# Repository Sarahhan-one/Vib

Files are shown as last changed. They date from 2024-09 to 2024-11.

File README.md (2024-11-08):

# Vib : Wearable Directional Assistant

Vib_rev2_animation
378704736-dd931122-ff3b-4bf1-a659-7b5e057d0389

## What is Vib? 
Vib is a ```wearable smart anklet``` that navigates the wearer using vibration. 
It houses ```three haptic motors``` facing three different directions – ```left```, ```forward```, and ```right``` – to convey an intuitive sense of direction. 
A smartphone connects to it and enables the navigator mode, as well as the customization of features.

## How it works? 
Vib is powered by a rechargeable battery that uses a type-C charger. The battery powers the microcontroller, the ATmega328P-AU, which controls all inputs and outputs used by Vib as well as the GPS and the bluetooth connection. 

The inputs to the devices are the GPS and the bluetooth signals. 
The bluetooth module allows the user to use the Vib app to cater the device to their needs, including setting the destination and the vibration intensity. 

As the device receives locational and direction information from the phone, it will send corresponding vibrational signals to vibrational motors installed at different sides of the device. 
As well, two LED lights are also used as the outputs of the microcontroller to indicate, for example, the bluetooth or battery status. 



## Future enhancements
* _Real-Time Location_ : Vib will have an embedded GPS module that allows user to track the location of the device real-time.
  This means one can easily find Vib device when lost, as well as the location of the other Vib it is connected to.
* _Connect to Another Vib via Bluetooth_ : Vib will provide an option to connect to another Vib, which allows one to find the location of the other Vib wearer through vibration.
* _Change Vibration Intensity_ : Through the Vib app, one will be able to easily change the vibration intensity. From workouts to daily walks, Vib can be felt in any environment.
* _Change Light Style_ : As well, Vib also offers diverse light modes. One will be able to choose to turn off the LEDs during the day and bright and festive at night.

## Flowchart 


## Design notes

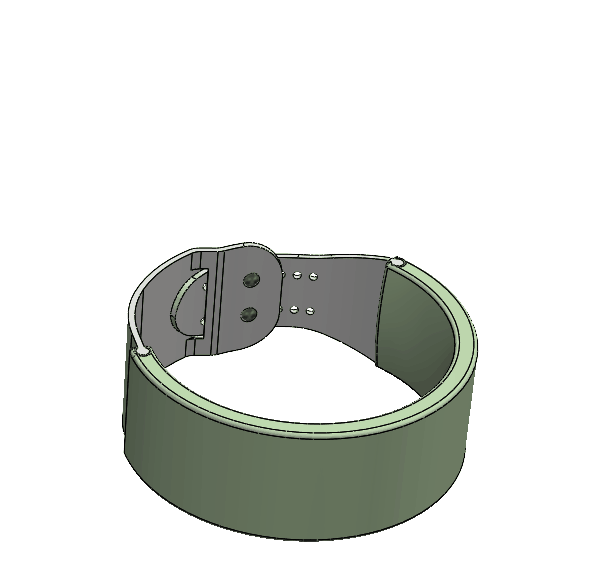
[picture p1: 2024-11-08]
Vib_rev2_explosion.gif

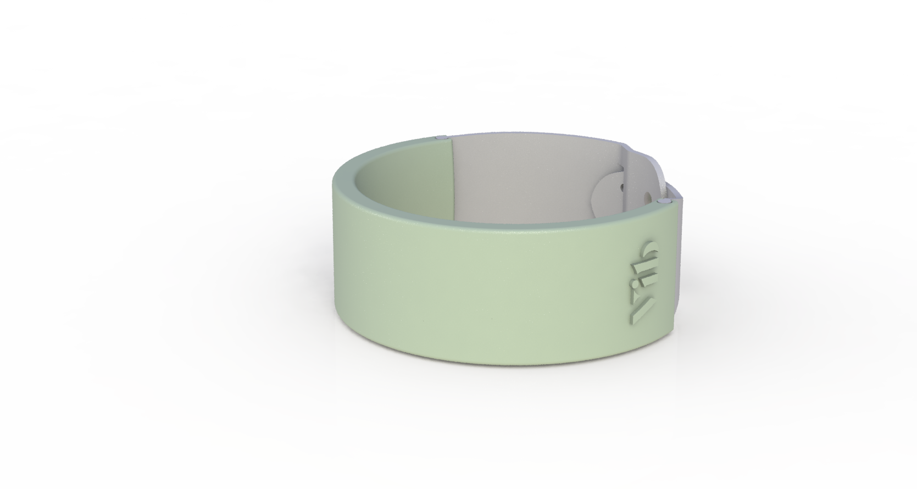
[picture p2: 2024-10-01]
SW_Vib/Vib_rev2/Vib_rev2_green_Studio.png

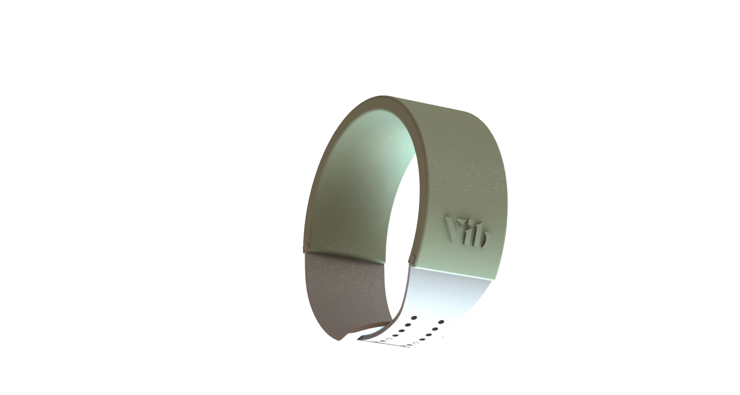
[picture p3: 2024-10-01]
SW_Vib/Vib_rev2/Vib_rev2_green.png

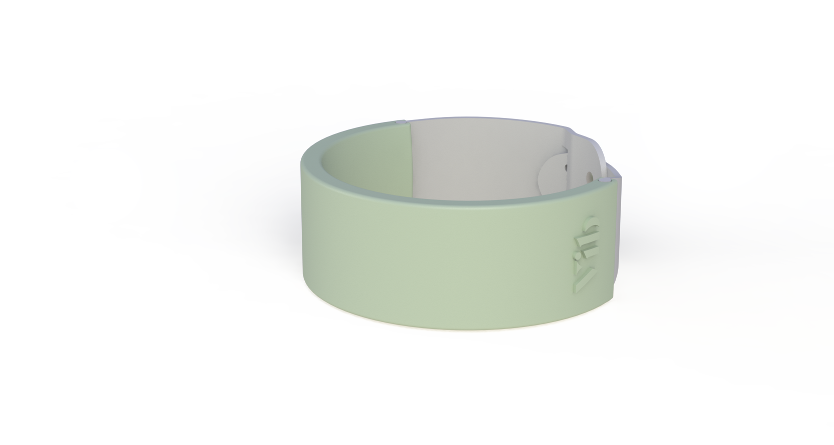
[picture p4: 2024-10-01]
SW_Vib/Vib_rev2/Vib_rev2_green_twolights.png

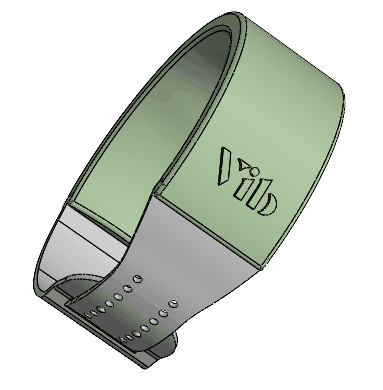
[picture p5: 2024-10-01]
SW_Vib/Vib_rev2/Vib_rev2_animation.gif

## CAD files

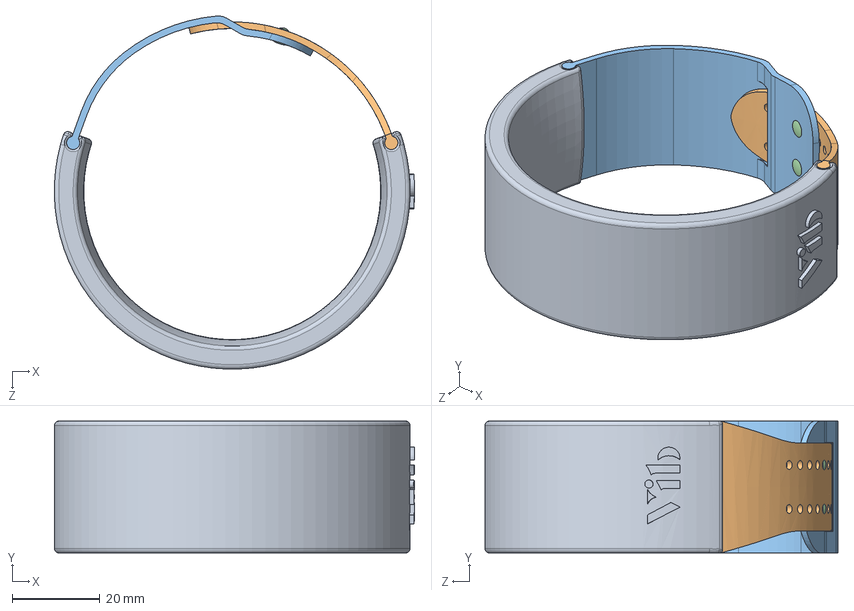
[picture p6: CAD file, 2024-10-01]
SW_Vib/Vib_rev2/SW_files/Vib_rev2.SLDASM
81.9 x 30.0 x 80.3 mm
Vib_Case_Silicon_rev2
NoBuckleStrap_Silicon
BuckleStrap_Silicon
Buckle_StainlessSteel x 2
2mm_Mini_Vibrating_Disk_Motor x 3
A1848_Battery x 2

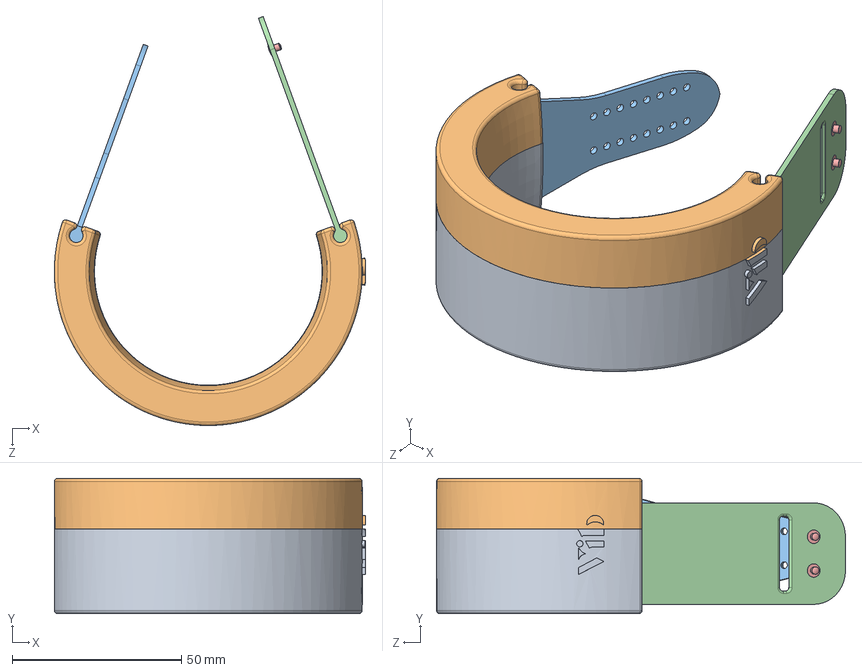
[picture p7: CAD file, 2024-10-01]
SW_Vib/Vib_printing/Vib_printing_SW/Vib_printing.SLDASM
92.0 x 40.0 x 120.8 mm
Vib_Case_printing_lower
Vib_Case_printing_upper
NoBuckleStrap_Silicon_flatten
BuckleStrap_flatten
Buckle_StainlessSteel x 2

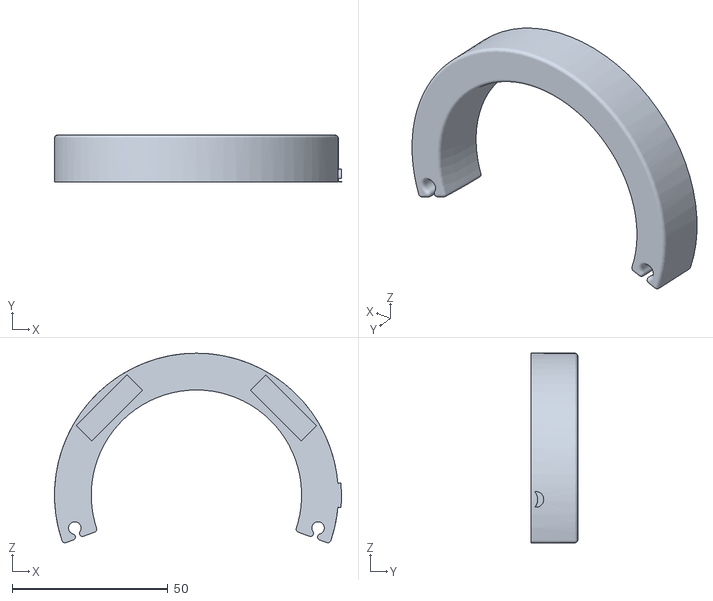
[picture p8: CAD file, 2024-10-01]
SW_Vib/Vib_printing/Vib_Case_printing_upper.STL
92.0 x 15.0 x 60.8

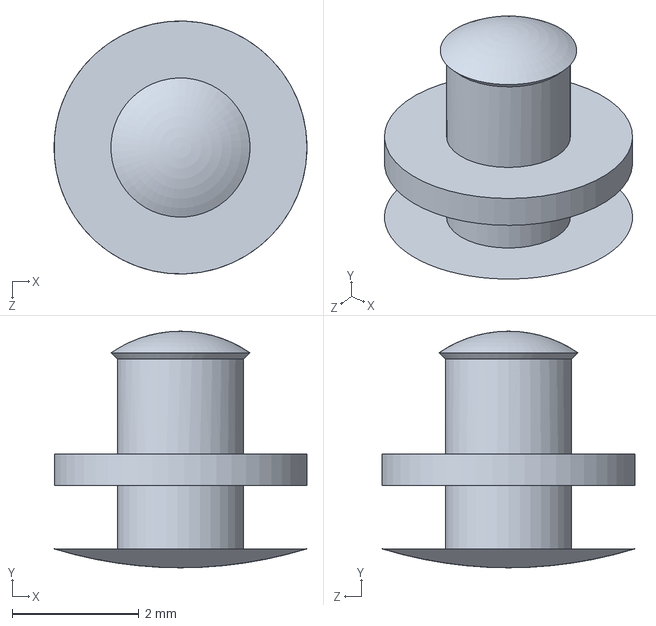
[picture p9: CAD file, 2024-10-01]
SW_Vib/Vib_printing/Vib_printing_SW/Buckle_StainlessSteel.SLDPRT
4.00 x 3.74 x 4.00 mm

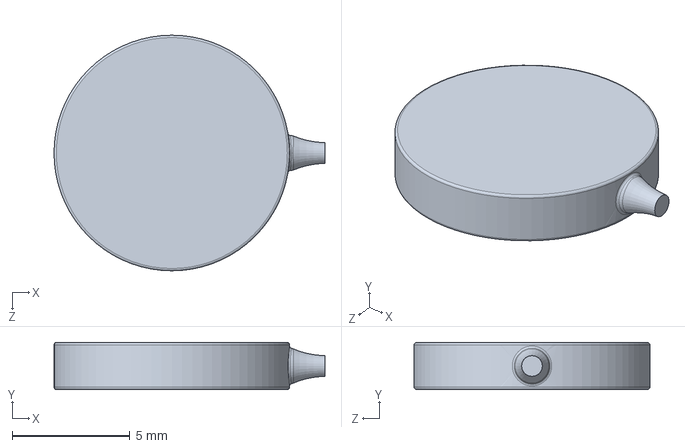
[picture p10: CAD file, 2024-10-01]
SW_Vib/Vib_rev2/SW_files/2mm_Mini_Vibrating_Disk_Motor.SLDPRT
11.5 x 2.00 x 10.0 mm

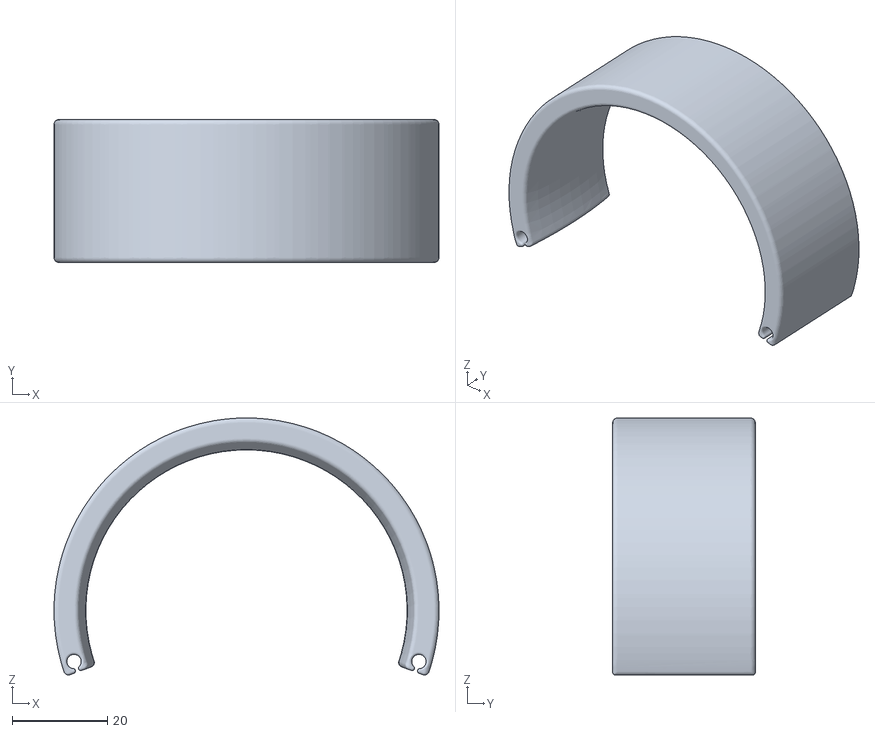
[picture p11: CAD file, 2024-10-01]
SW_Vib/Vib_rev2/Vib_Case_Silicon_rev2.STL
80.9 x 30.0 x 54.0

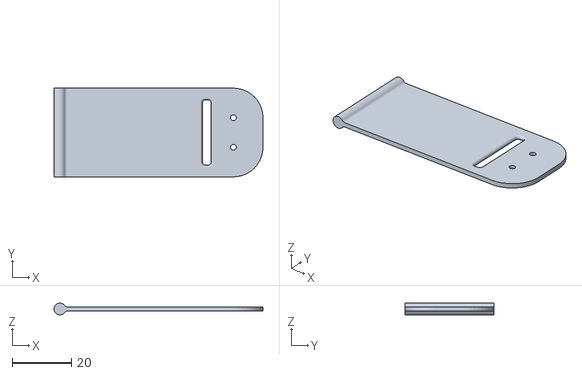
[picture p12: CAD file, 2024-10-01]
SW_Vib/Vib_printing/BuckleStrap_flatten.STL
70.7 x 30.0 x 3.99

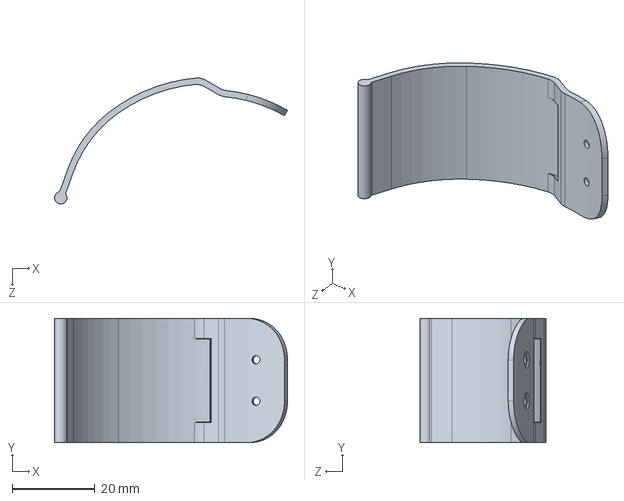
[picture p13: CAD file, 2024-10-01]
SW_Vib/Vib_rev2/SW_files/BuckleStrap_Silicon.SLDPRT
56.1 x 30.0 x 30.4 mm

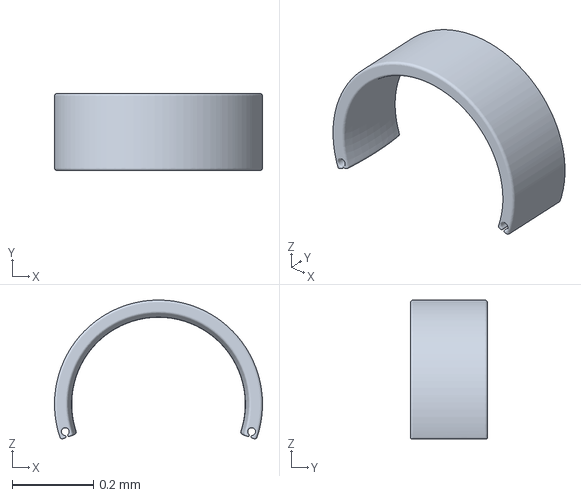
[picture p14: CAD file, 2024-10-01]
SW_Vib/Vib_rev2/Vib_Case_Silicon_rev2_green.3mf
0.512 x 0.19 x 0.342 mm

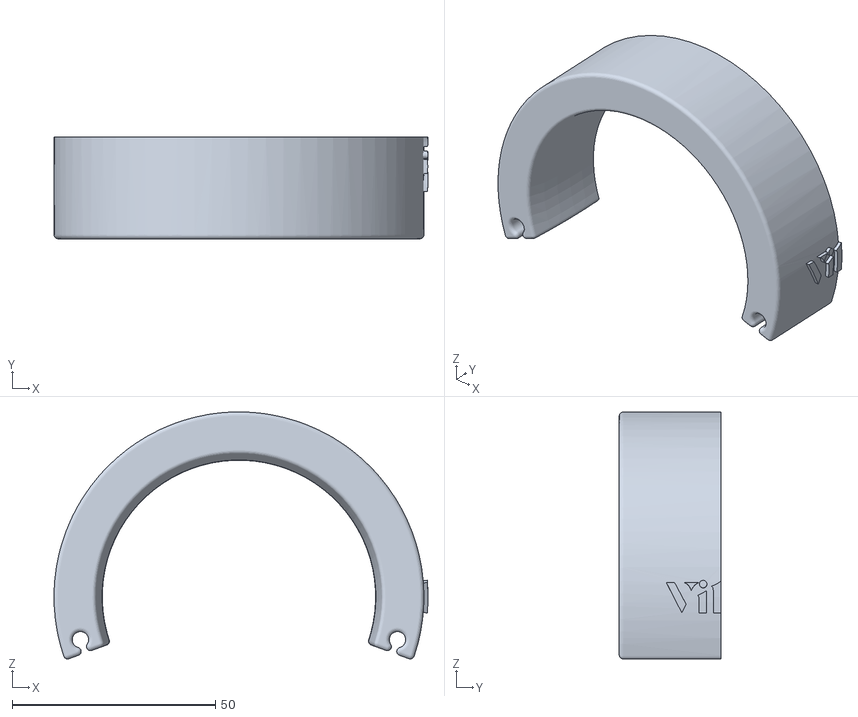
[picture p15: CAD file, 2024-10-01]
SW_Vib/Vib_printing/Vib_Case_printing_lower.STL
92.0 x 25.0 x 60.8

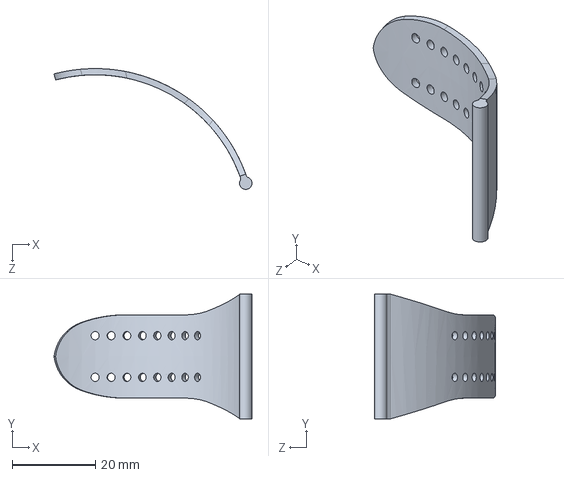
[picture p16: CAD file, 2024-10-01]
SW_Vib/Vib_printing/Vib_printing_SW/NoBuckleStrap_Silicon.SLDPRT
47.5 x 30.0 x 29.0 mm

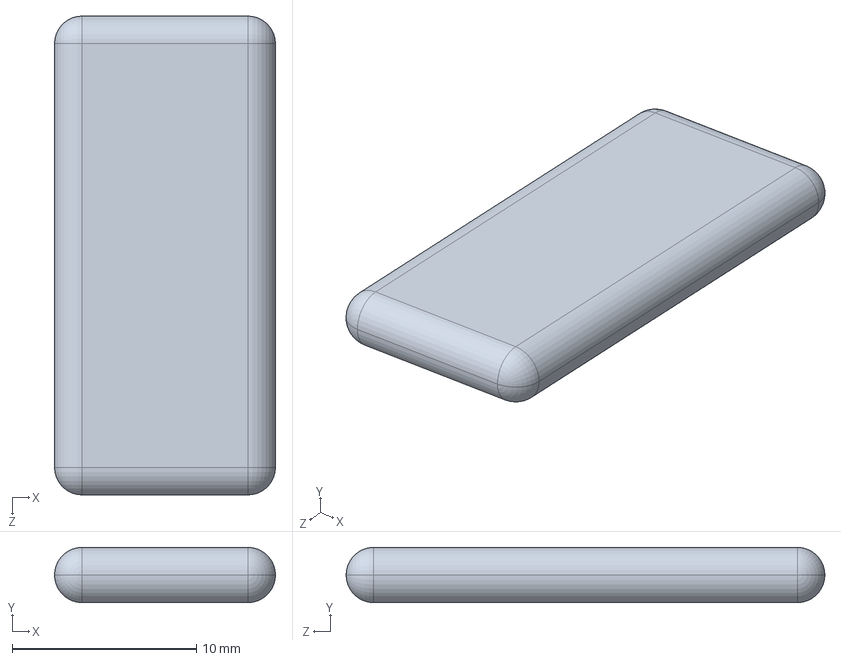
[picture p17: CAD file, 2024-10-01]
SW_Vib/Vib_rev2/SW_files/A1848_Battery.SLDPRT
12.0 x 3.00 x 26.0 mm

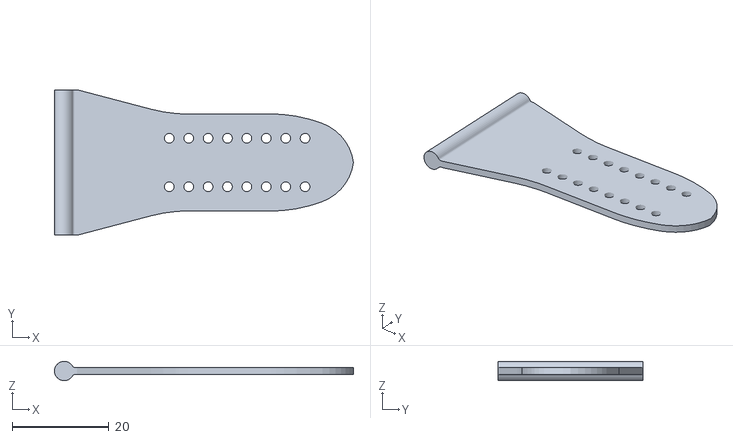
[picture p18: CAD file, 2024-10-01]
SW_Vib/Vib_printing/NoBuckleStrap_Silicon_flatten.STL
61.7 x 30.0 x 4.00

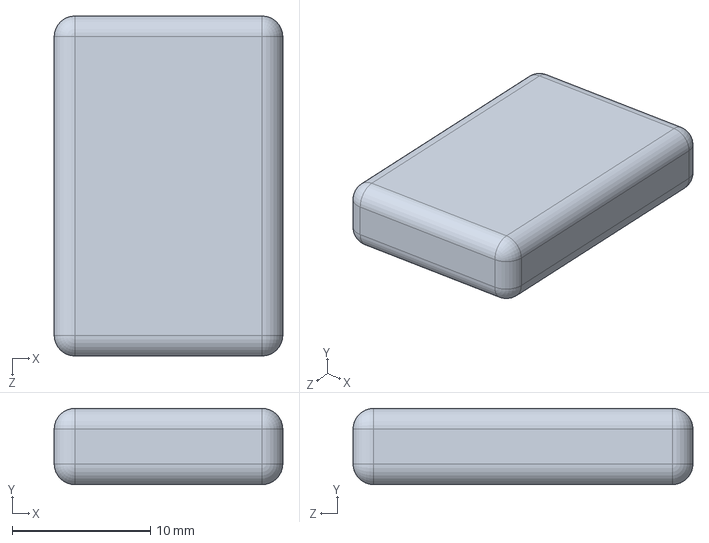
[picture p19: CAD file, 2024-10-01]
SW_Vib/Vib_rev2/SW_files/ElectronicComponents.SLDPRT
16.6 x 5.52 x 24.6 mm

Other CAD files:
SW_Vib/Vib_printing/Vib_printing_SW/Vib_Case_printing_upper.SLDPRT
SW_Vib/Vib_printing/Vib_printing_SW/NoBuckleStrap_Silicon_flatten.SLDPRT
SW_Vib/Vib_printing/Vib_printing_SW/Vib_Case_printing_lower.SLDPRT
SW_Vib/Vib_printing/Vib_printing_SW/BuckleStrap_Silicon.SLDPRT
SW_Vib/Vib_printing/Vib_printing_SW/BuckleStrap_flatten.SLDPRT
SW_Vib/Vib_printing/Vib_printing_SW/Vib_Case_printing.SLDPRT
SW_Vib/Vib_rev0/SW Files/2mm_Mini_Vibrating_Disk_Motor.SLDPRT
SW_Vib/Vib_rev0/SW Files/Electrical_Components.SLDPRT
SW_Vib/Vib_rev0/SW Files/Electrical_Components_Case.SLDPRT
SW_Vib/Vib_rev0/SW Files/Flexible_Band.SLDPRT
SW_Vib/Vib_rev0/SW Files/Vib.SLDASM
SW_Vib/Vib_rev0/SW Files/Vib_Case.SLDPRT
SW_Vib/Vib_rev1/2mm_Mini_Vibrating_Disk_Motor.SLDPRT
SW_Vib/Vib_rev1/A1848_Battery.SLDPRT
SW_Vib/Vib_rev1/Apple_Watch_40mm_dimensions.SLDPRT
SW_Vib/Vib_rev1/Vib_Case_Silicon_rev1.SLDPRT
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

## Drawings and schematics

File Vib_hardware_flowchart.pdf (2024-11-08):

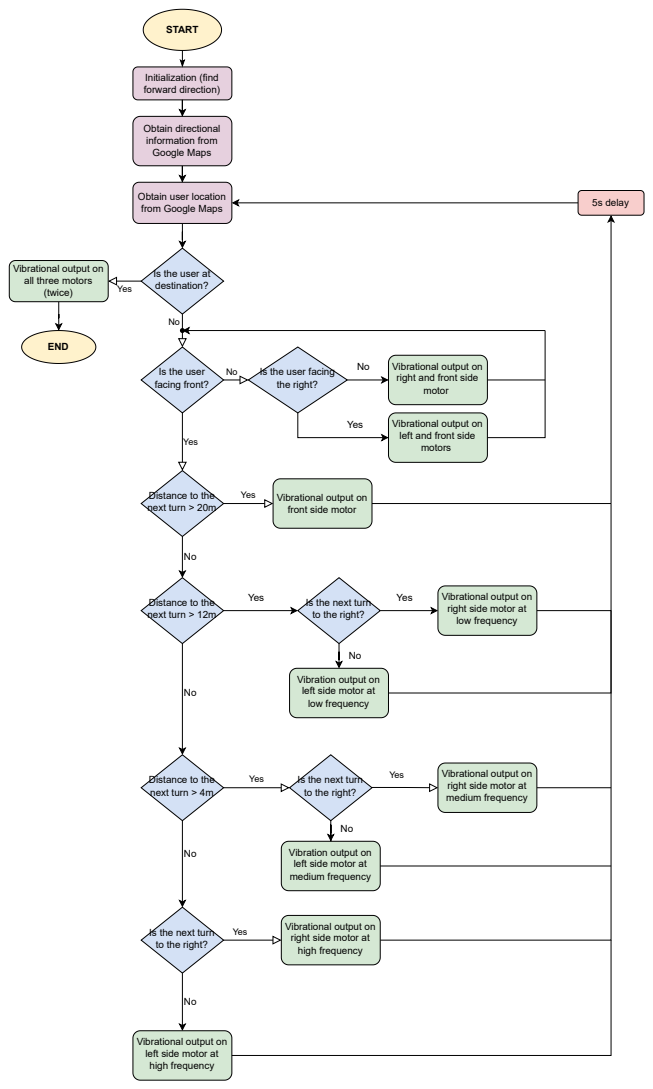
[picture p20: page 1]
Initialization (find forward direction); Obtain directional information from Google Maps; Yes; 5s delay; START; END

Obtain user location
from Google Maps

Vibrational output on
all three motors
(twice)

Is the user at
destination?

Is the user
facing front?

Is the user facing
the right?

right and front side
motor

left and front side
motors

Distance to the
next turn > 20m

front side motor

right side motor at
low frequency

next turn > 12m

Is the next turn
to the right?

Vibration output on
left side motor at

medium frequency

next turn > 4m

high frequency

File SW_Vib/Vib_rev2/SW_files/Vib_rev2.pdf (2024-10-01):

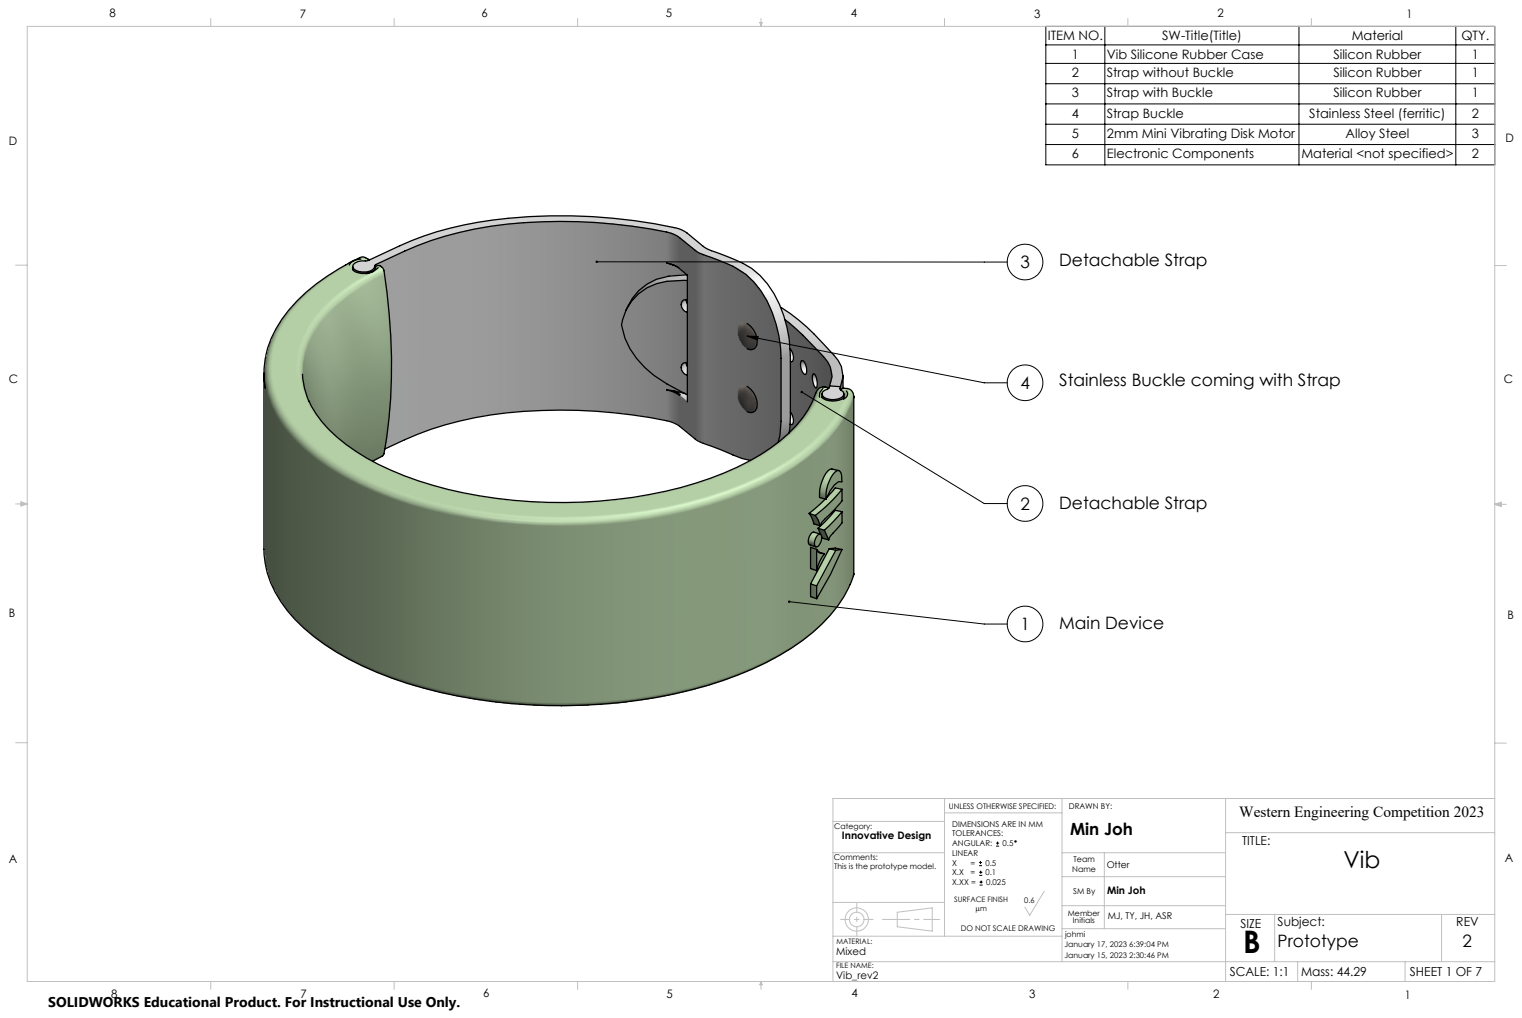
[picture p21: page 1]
Main Device; Detachable Strap; DRAWN BY:; SCALE: 1:1 Mass: 44.29; Vib_rev2; SHEET 1 OF 7; January 15, 2023 2:30:46 PM; January 17, 2023 6:39:04 PM; Min Joh; FILE NAME:

ITEM NO. | SW-Title(Title) | Material | QTY.
1 | Vib Silicone Rubber Case | Silicon Rubber | 1
2 | Strap without Buckle | Silicon Rubber | 1
3 | Strap with Buckle | Silicon Rubber | 1
4 | Strap Buckle | Stainless Steel (ferritic) | 2
5 | 2mm Mini Vibrating Disk Motor | Alloy Steel | 3
6 | Electronic Components | Material <not specified> | 2

Stainless Buckle coming with Strap

UNLESS OTHERWISE SPECIFIED:
DIMENSIONS ARE IN MM
TOLERANCES:
ANGULAR: 0.5
LINEAR
SURFACE FINISH

Western Engineering Competition 2023
TITLE:

Category:
Innovative Design
Vib Comments:
This is the prototype model.

MJ, TY, JH, ASR

DO NOT SCALE DRAWING

SOLIDWORKS Educational Product. For Instructional Use Only.

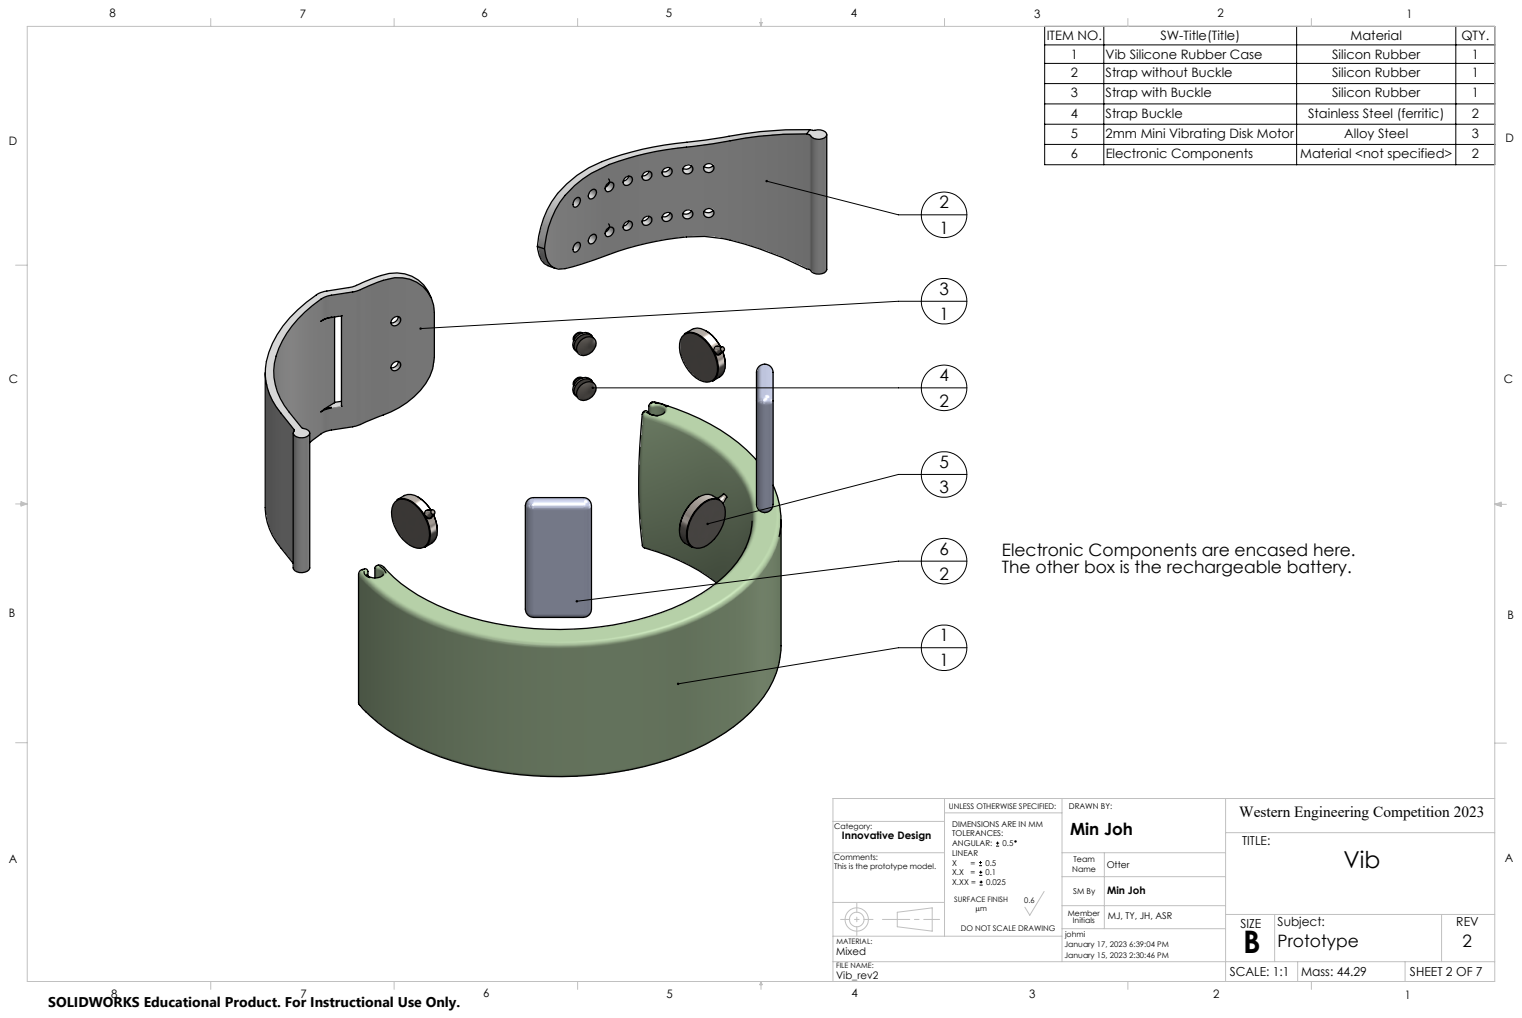
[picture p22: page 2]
DRAWN BY:; SCALE: 1:1 Mass: 44.29; Vib_rev2; SHEET 2 OF 7; January 15, 2023 2:30:46 PM; January 17, 2023 6:39:04 PM; Min Joh

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

Electronic Components are encased here.
The other box is the rechargeable battery.

UNLESS OTHERWISE SPECIFIED:
DIMENSIONS ARE IN MM
TOLERANCES:
ANGULAR: 0.5
LINEAR
SURFACE FINISH

Western Engineering Competition 2023
TITLE:

Category:
Innovative Design
Vib Comments:
This is the prototype model.

MJ, TY, JH, ASR

DO NOT SCALE DRAWING

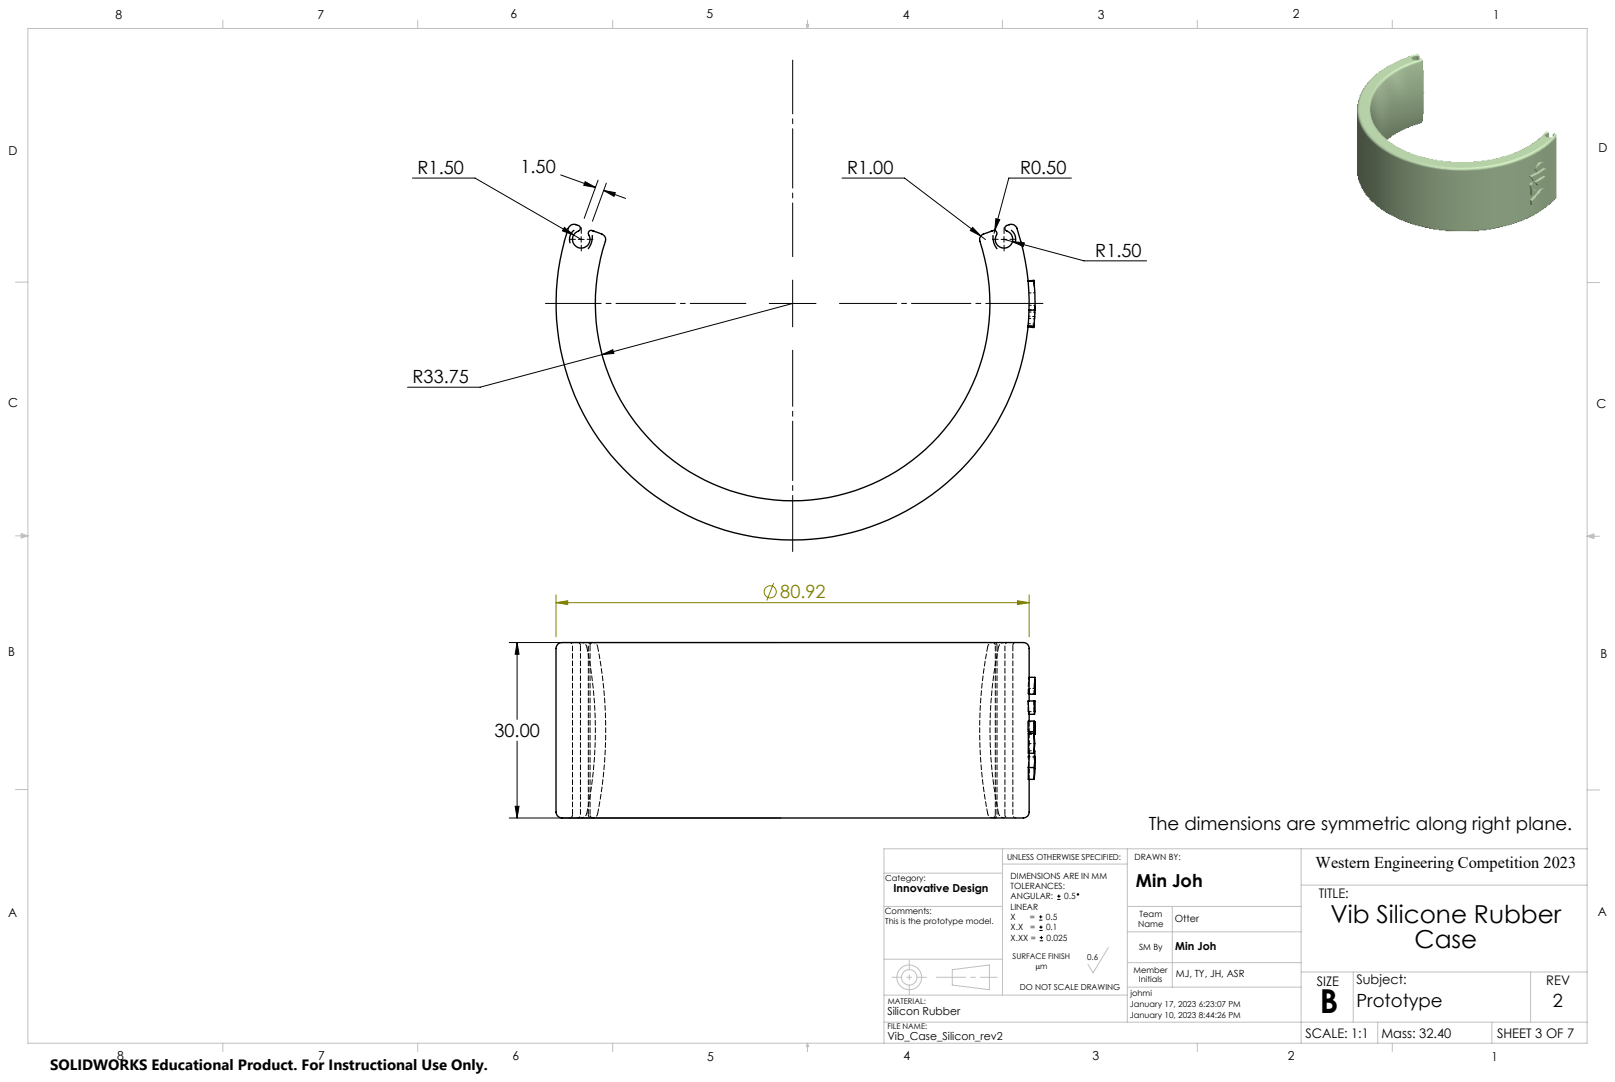
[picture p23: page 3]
Silicon Rubber; DRAWN BY:; SCALE: 1:1 Mass: 32.40; Vib_Case_Silicon_rev2; SHEET 3 OF 7; January 10, 2023 8:44:26 PM; January 17, 2023 6:23:07 PM; Min Joh; Innovative Design

The dimensions are symmetric along right plane.

UNLESS OTHERWISE SPECIFIED:
DIMENSIONS ARE IN MM
TOLERANCES:
ANGULAR: 0.5
LINEAR
SURFACE FINISH

Western Engineering Competition 2023
TITLE:
Vib Silicone Rubber
Case

Comments:
This is the prototype model.

MJ, TY, JH, ASR

DO NOT SCALE DRAWING

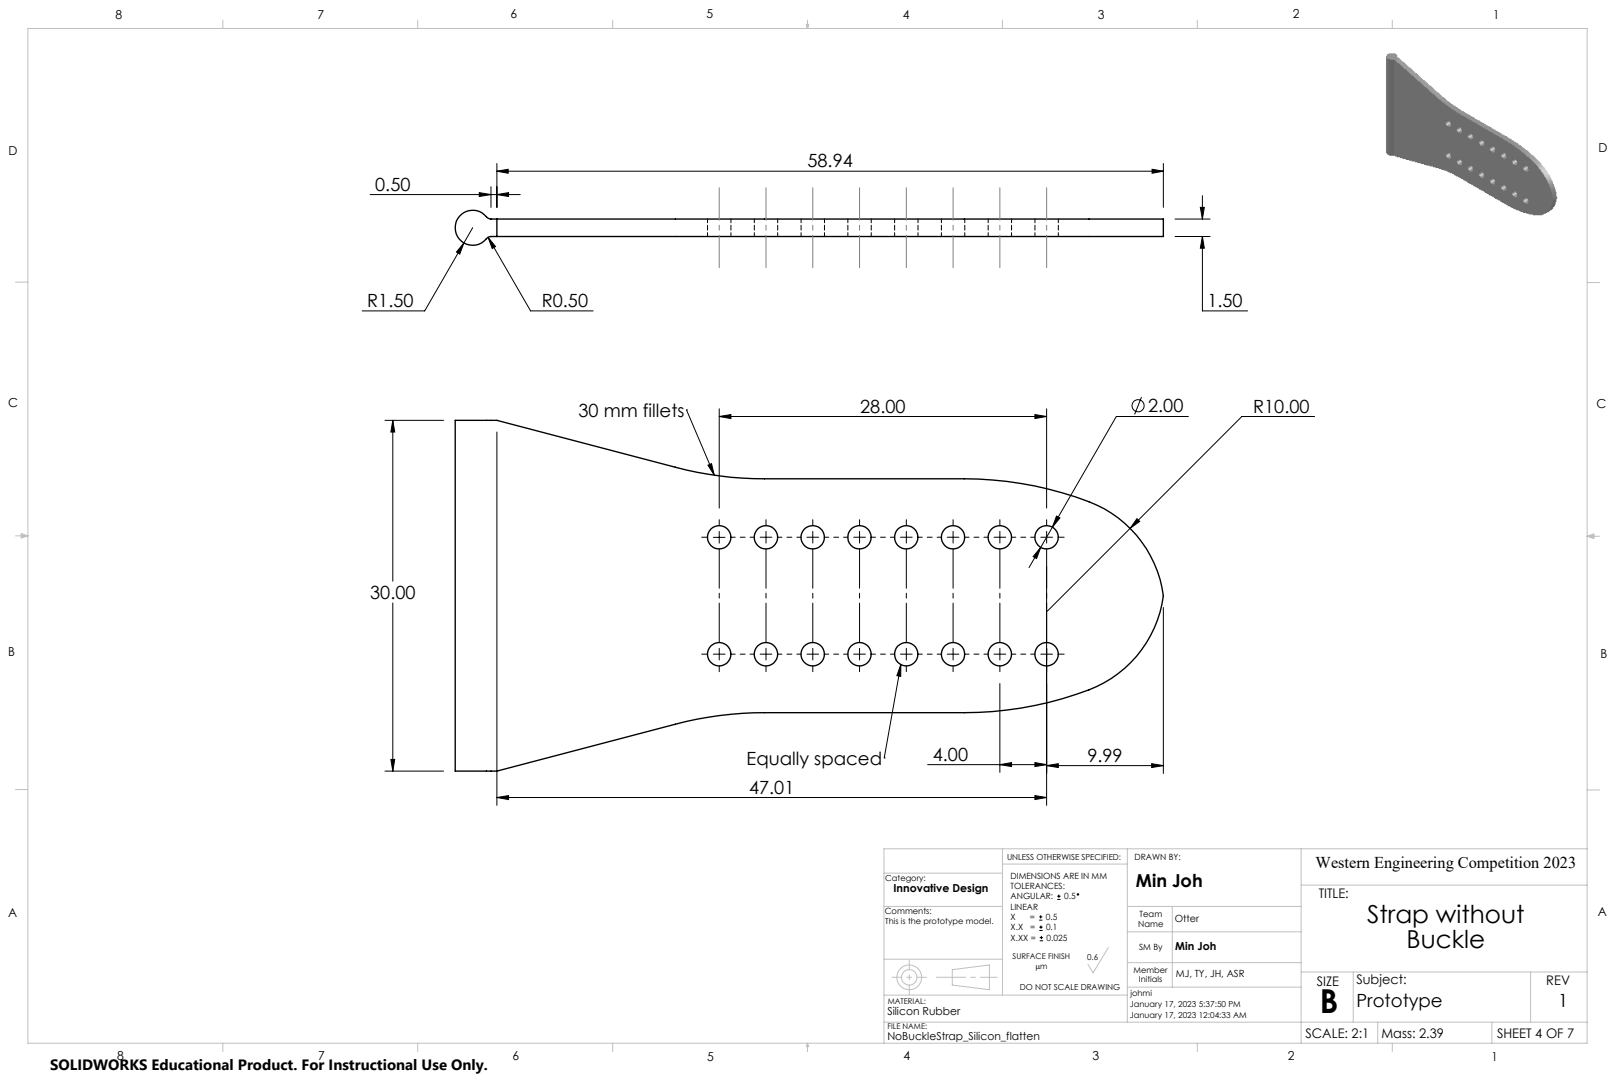
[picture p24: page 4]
Equally spaced; 30 mm fillets; Silicon Rubber; DRAWN BY:; Western Engineering Competition 2023; SCALE: 2:1 Mass: 2.39; NoBuckleStrap_Silicon_flatten; SHEET 4 OF 7; Strap without; January 17, 2023 12:04:33 AM; January 17, 2023 5:37:50 PM; Min Joh; Innovative Design

UNLESS OTHERWISE SPECIFIED:
DIMENSIONS ARE IN MM
TOLERANCES:
ANGULAR: 0.5
LINEAR
SURFACE FINISH

Comments:
This is the prototype model.

MJ, TY, JH, ASR

DO NOT SCALE DRAWING

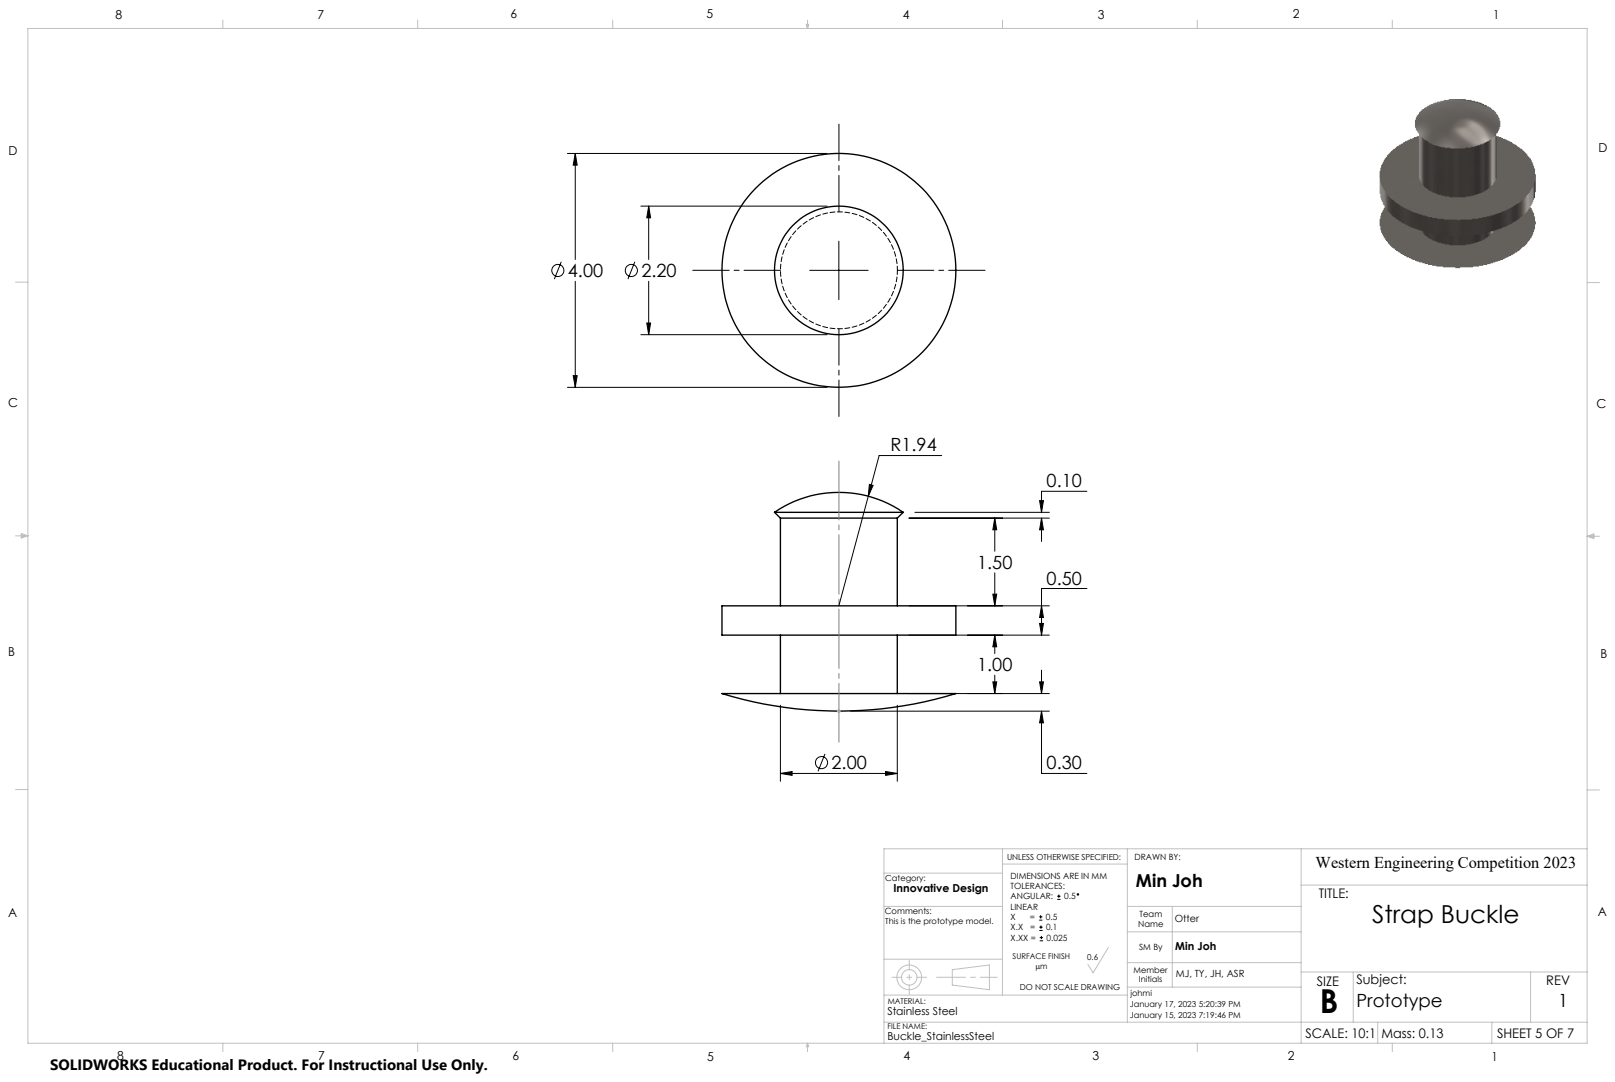
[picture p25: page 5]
Stainless Steel; DRAWN BY:; SCALE: 10:1 Mass: 0.13; Buckle_StainlessSteel; SHEET 5 OF 7; January 15, 2023 7:19:46 PM; January 17, 2023 5:20:39 PM; Min Joh

UNLESS OTHERWISE SPECIFIED:
DIMENSIONS ARE IN MM
TOLERANCES:
ANGULAR: 0.5
LINEAR
SURFACE FINISH

Western Engineering Competition 2023
TITLE:

Category:
Innovative Design
Strap Buckle Comments:
This is the prototype model.

MJ, TY, JH, ASR

DO NOT SCALE DRAWING

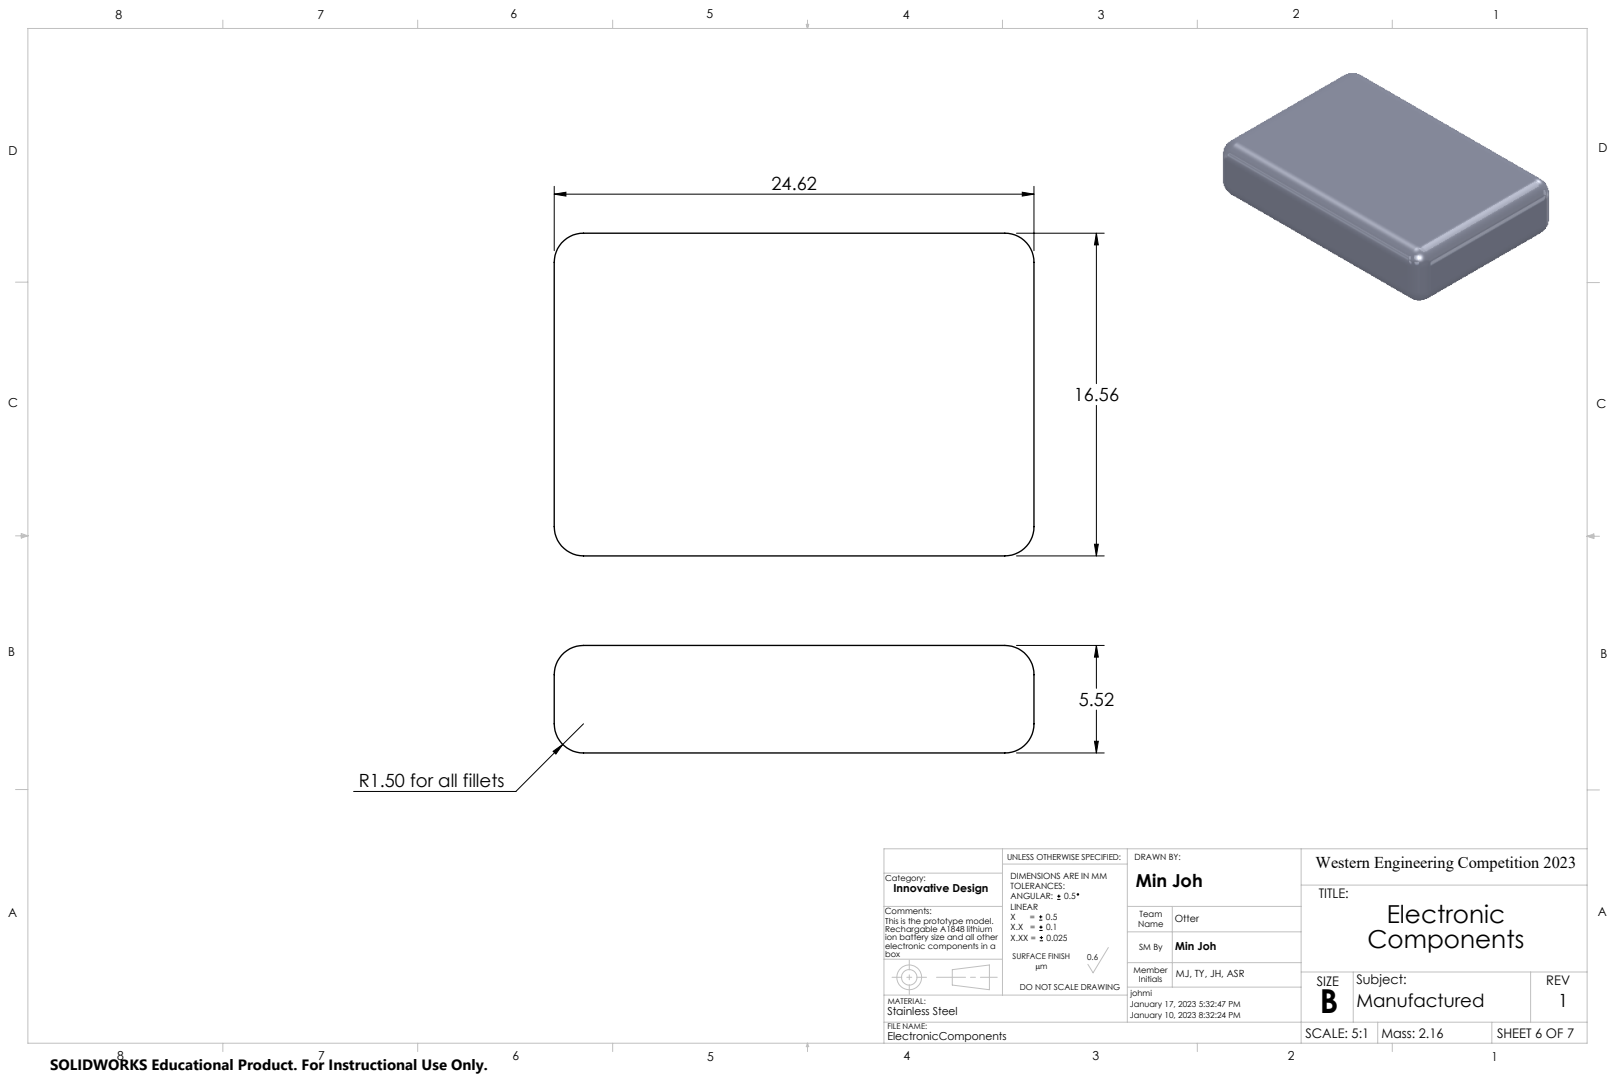
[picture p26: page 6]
DRAWN BY:; Western Engineering Competition 2023; SCALE: 5:1 Mass: 2.16; ElectronicComponents; SHEET 6 OF 7; box; SURFACE FINISH; January 10, 2023 8:32:24 PM; January 17, 2023 5:32:47 PM; Min Joh; Innovative Design

R1.50 for all fillets

UNLESS OTHERWISE SPECIFIED:
DIMENSIONS ARE IN MM
TOLERANCES:
ANGULAR: 0.5
LINEAR

Comments:
This is the prototype model.
Rechargable A1848 lithium
ion battery size and all other
electronic components in a

MJ, TY, JH, ASR

DO NOT SCALE DRAWING

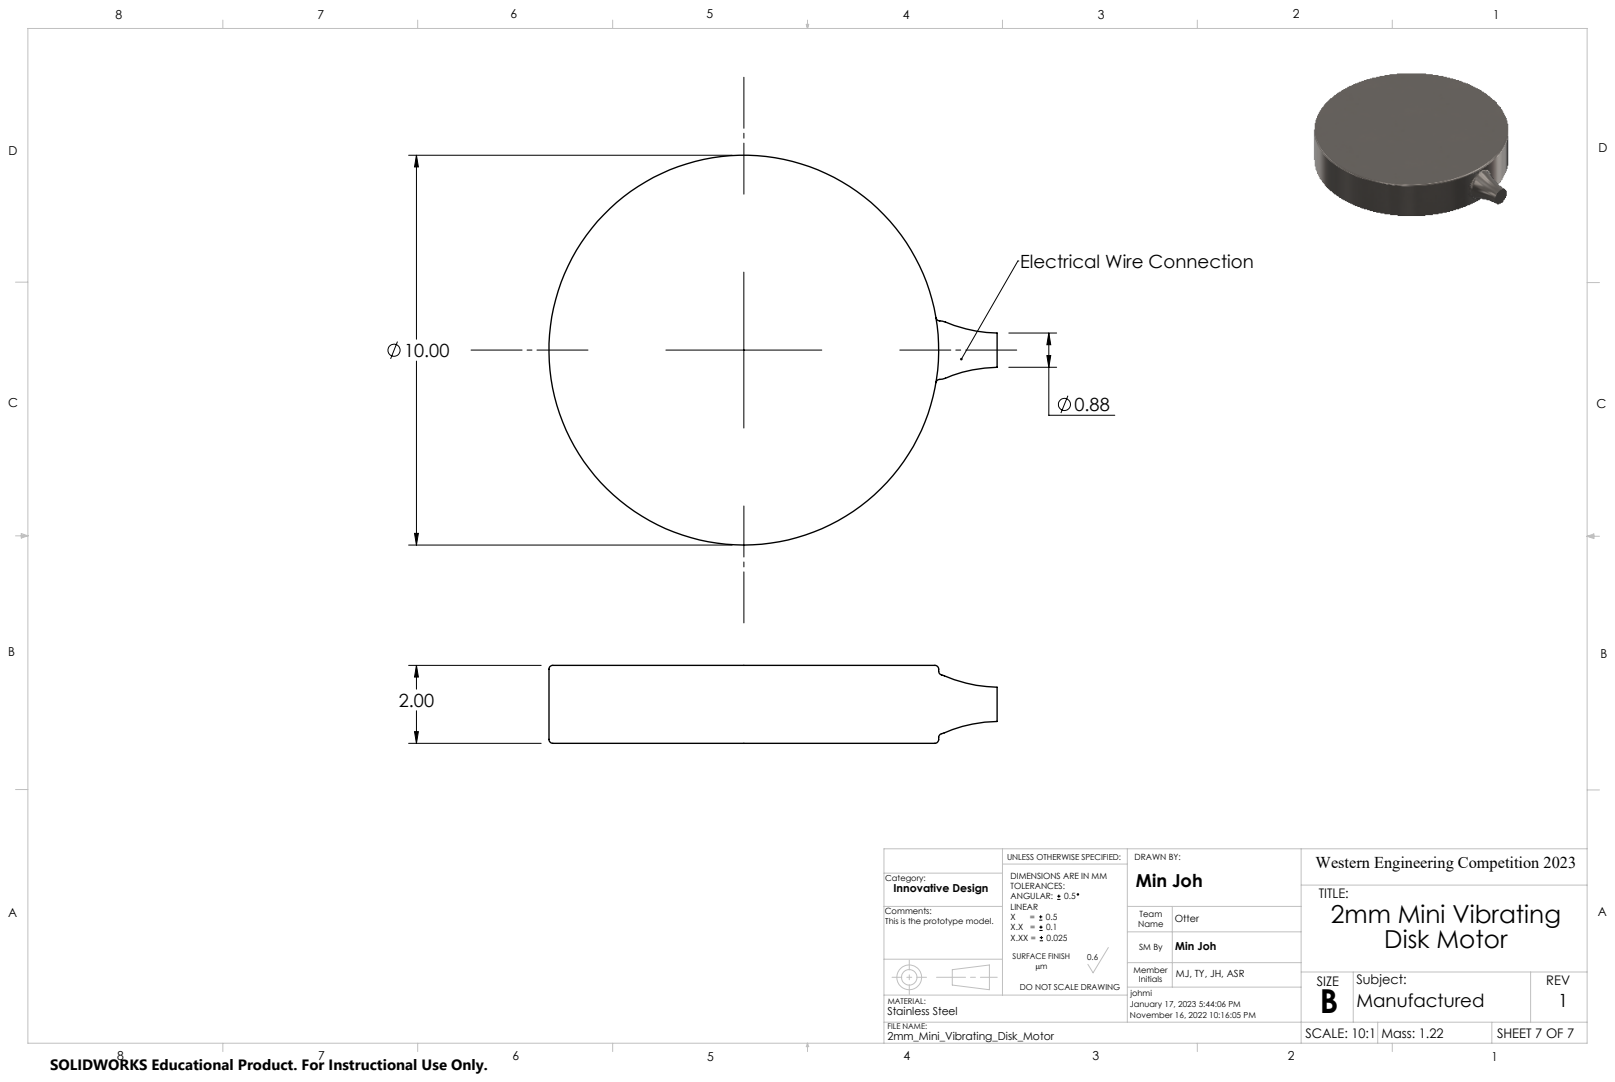
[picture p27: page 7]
DRAWN BY:; SCALE: 10:1 Mass: 1.22; 2mm_Mini_Vibrating_Disk_Motor; SHEET 7 OF 7; November 16, 2022 10:16:05 PM; January 17, 2023 5:44:06 PM; Min Joh; Innovative Design

Electrical Wire Connection

UNLESS OTHERWISE SPECIFIED:
DIMENSIONS ARE IN MM
TOLERANCES:
ANGULAR: 0.5
LINEAR
SURFACE FINISH

Western Engineering Competition 2023
TITLE:
2mm Mini Vibrating
Disk Motor

Comments:
This is the prototype model.

MJ, TY, JH, ASR

DO NOT SCALE DRAWING

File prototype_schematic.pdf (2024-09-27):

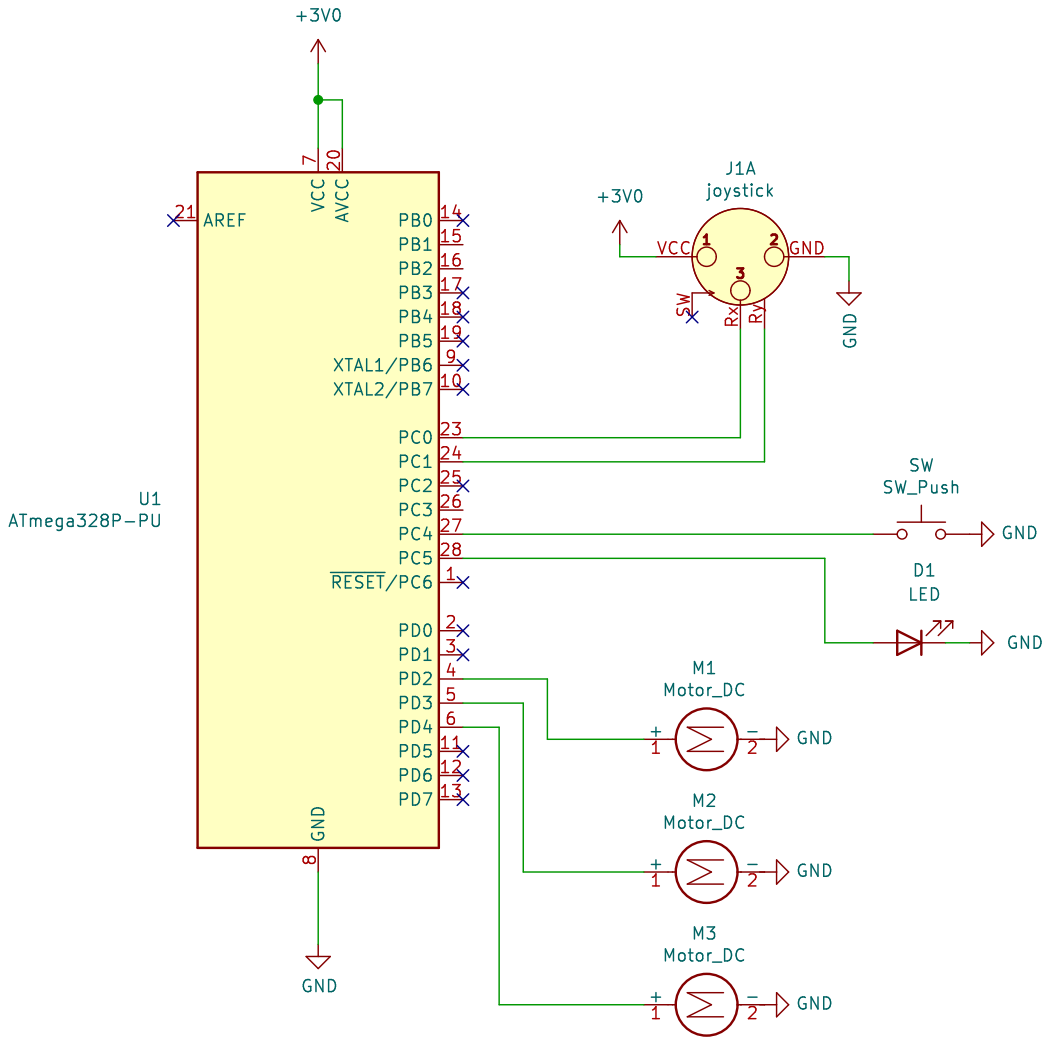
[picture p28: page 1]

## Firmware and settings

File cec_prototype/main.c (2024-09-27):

/* 
 * CEC VIB prototype
 * Adding bluetooth interface HC-05 to give directional information via laptop
 */

#define F_CPU 8000000UL
#define __DELAY_BACKWARD_COMPATIBLE__

#include <stdio.h>
#include <stdlib.h>
#include <avr/io.h>
#include <util/delay.h>


#define UBRRVAL 51 //initialize USART with 9600 baud rate

//Define input pins
#define SW PC4
#define RX PD0 
#define TX PD1

//Define output pins
#define LED PC5 //LED output
#define STR PD2 //Motor outputs
#define LEFT PD3
#define RIGHT PD4

//Define variables 
uint16_t intensity = 100;
unsigned char  rxdata; 

//Define messages 
unsigned char defaultmsg[] = "Directional Information: \n";

static void init(){
    PORTC &= ~(1<<SW); // ip starts low
    PORTD &= ~((1<<LED)|(1<<STR)|(1<<LEFT)|(1<<RIGHT)); //op starts LOW
    
    DDRC &= ~(1<<SW); // set switch as ip
    DDRD |= ((1<<LED)|(1<<STR)|(1<<LEFT)|(1<<RIGHT)); //set pins as ops
}

void usart_init(void) {
    UBRR0H = (unsigned char)(UBRRVAL>>8); //baud rate register high
    UBRR0L = (unsigned char)UBRRVAL; //baud rate register low
    UCSR0B |= (1<<TXEN0) | (1<<RXEN0); //enable transmitter and receiver
    UCSR0C |= (1<<UCSZ01) | (1<<UCSZ00); //set data frame format: asynchronous mode, no parity, 1 stop bit, 8 bit size
}


unsigned char receivebyte(void) {
    while(!(UCSR0A & (1<<RXC0))); //check all the data is received 
        return UDR0; 
}

static void vibration_on(rxdata, intensity){
    if (rxdata == 'f'){
        PORTD |= (1<<STR);
        _delay_ms(intensity*3);
        PORTD &= ~(1<<STR);
        _delay_ms(intensity*3);
        
        sendstr(defaultmsg); //messages
    } 
    else if (rxdata == 'l') {
        PORTD |= (1<<LEFT);
        _delay_ms(intensity*3);
        PORTD &= ~(1<<LEFT);
        _delay_ms(intensity*3);
        
        sendstr(defaultmsg); //messages  
    } 
    else if (rxdata == 'r') {
        PORTD |= (1<<RIGHT);
        _delay_ms(intensity*3);
        PORTD &= ~(1<<RIGHT);
        _delay_ms(intensity*3);
        
        sendstr(defaultmsg); //messages
    } 
}

static void intensity_on() {//change the vibration intensity
    switch (intensity) {
        case 100: 
            intensity = 500; 
            PORTC |= (1<<LED);//LED ON 
            break; 
        case 500: 
            intensity = 100; 
            PORTC &= ~(1<<LED);//LED OFF
            break; 
    }
}

void sendbyte(unsigned char MSG) {
    while((UCSR0A&(1<<UDRE0))==0);//check if data register, UDR0, is ready to receive new data 
    UDR0 = MSG; 
}

void sendstr(unsigned char *s) {
    unsigned char i = 0;
    while(s[i] != '\0'){
        sendbyte(s[i]);
        i++;
    }
}

int main(){
    init();
    usart_init();
    
    while(1){
        
        rxdata = receivebyte(); //receive the directional input via bluetooth
        
        if (!(PINC&(1<<SW))){ //if switch is pressed (low)
            _delay_ms(100);
            if (PINC&(1<<SW)){ //switch released (High))
                intensity_on();
            }
        }
        vibration_on(rxdata, intensity); //motor vibrates accordingly
    }
    return 0;
}

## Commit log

2024-09-27 add c file
    this is prototype version for cec
2024-09-27 add schematic file
    this is the prototype schematic file for cec
2024-10-01 Upload SW files
    This upload includes STL files, rendered images, and Vib's SolidWorks model revisions.
    [2mm_Mini_Vibrating_Disk_Motor.SLDPRT, A1848_Battery.SLDPRT, Apple_Watch_40mm_dimensions.SLDPRT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]
